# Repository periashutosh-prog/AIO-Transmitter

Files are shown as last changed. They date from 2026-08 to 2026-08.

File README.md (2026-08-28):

<div align="center">

# AIO Transmitter (AIO-TX)

**An open-source, multi-protocol wireless control platform built around the ESP32-C6**



[]()

[Website](https://aio-transmitter.vercel.app) · [Full Documentation](AIO-Transmitter-Documentation.md) · [StrawberryOS Ecosystem](https://github.com/periashutosh-prog/StrawberryOS) · [Smart_Connect Library](https://github.com/periashutosh-prog/Smart-Connect)

</div>

---

## What is AIO-TX?

AIO Transmitter is a universal wireless control interface — not a remote built for one job, but a modular platform that adapts to whatever you're building: an RC vehicle, a robot, a wireless HID peripheral, or a custom ESP-based project of your own.

It's built around the **ESP32-C6**, giving it native support for **WiFi 6, Bluetooth Low Energy, and ESP-NOW** in one board, plus a standalone **0.96" OLED interface** for configuring modes, profiles, and control mappings without ever needing a laptop or companion app.

The platform is designed for two audiences at once: makers and developers who want to fork the fully open hardware and firmware, and beginners who can start controlling something in minutes using preset protocol profiles with no wireless-protocol expertise required.

---

## ✅ Key Features

- **Multi-protocol wireless communication** — WiFi 6, BLE, and ESP-NOW on a single board, with CAN Bus planned for REV 3.0
- **Dual pairing modes** — a fast, unauthenticated **ESP-NOW** mode for trusted low-latency setups, and a PIN-authenticated **Smart Connect** mode for secured sessions
- **Standalone onboard UI** — a 0.96" OLED handles mode switching, WiFi setup, live telemetry, and built-in apps, with no external device required
- **BLE HID emulation** — the same hardware functions as a wireless mouse, keyboard, or media remote for PCs, TVs, and mobile devices
- **17 tactile inputs** — dual D-pads, dual simulated analog channels, and system controls, all read through a single I2C MCP23017 expander (plus one native-GPIO system button)
- **Live link-quality telemetry** — round-trip ping and packet-loss percentage, tracked and shown in real time during an active session
- **Command-silence watchdog** — both transmitter and receiver detect a stalled link and safely end the session, instead of a controlled device executing a stale last command indefinitely
- **Rechargeable battery system** — USB-C charging, with REV 2.0 adding integrated I2C battery telemetry
- **Open, extensible receiver ecosystem** — the companion [`Smart_Connect`](https://github.com/periashutosh-prog/Smart-Connect) library (ESP32 + ESP8266) lets anyone build a compatible receiver — for a robot, an RC car, or any project of their own — with almost no glue code

---

## 🧩 Hardware Revisions

| | REV 1.0 | REV 2.0 |
|---|---|---|
| **Approach** | Module-based (proves the concept) | Discrete-IC based (production-oriented redesign) |
| **MCU** | Seeed XIAO ESP32-C6 breakout | Bare ESP32-C6-MINI-1U module, custom PCB |
| **Power management** | TP4056 charger + MT3608 boost | IP5306-I2C (charge + boost + battery telemetry) |
| **Antenna** | Onboard PCB trace only | Onboard trace + external IPEX-to-SMA option |
| **Enclosure** | SLA resin | CNC-machined aluminum |

REV 2.0 exists specifically to bridge REV 1.0 and REV 3.0: REV 1.0 proved the concept using off-the-shelf modules, and REV 3.0's goal — full CAN Bus modularity with plug-and-play expansion — requires the discrete-IC design competency REV 2.0 is built to develop.

Full architecture, pairing flow, and design rationale: see [AIO-Transmitter-Documentation.md](AIO-Transmitter-Documentation.md).

---

## 🚗 Receiver Ecosystem

AIO-TX is only half the system — the [`Smart_Connect`](https://github.com/periashutosh-prog/Smart-Connect) library is the receiver-side counterpart, available for both **ESP32** and **ESP8266**. It handles advertising, handshake, PIN authentication, and telemetry replies, so a receiver project only needs to implement its own control logic (driving motors, actuators, etc.) on top of it.

An example receiver — an ESP8266-based RC car using an L298N motor driver — is part of this ecosystem, demonstrating full differential steering (forward/back/left/right), live motor-status telemetry back to the transmitter, and an automatic failsafe that cuts motors if the wireless link drops.

---

## 🚀 Getting Started

1. **Get the PCB files** — fabricate from the schematics in `Hardware Design Files/` via JLCPCB or any manufacturer.
2. **Assemble the board** — REV 1.0 is hand-solderable; a full BOM is provided.
3. **Flash the firmware** — compile `AIO_Transmitter.ino` yourself, or use the web-based flashing tool at [aio-transmitter.vercel.app](https://aio-transmitter.vercel.app).
4. **Print the enclosure** — design files included.

Full step-by-step build instructions: [AIO-Transmitter-Documentation.md](AIO-Transmitter-Documentation.md#-how-to-make-aio-transmitter-rev-10).

---

## 🌱 Part of the StrawberryOS Ecosystem

AIO-TX is built on shared firmware architecture and design language from [**StrawberryOS**](https://github.com/periashutosh-prog/StrawberryOS), an open ecosystem of modular embedded devices — including an earlier project, **StrawberryWatch** (originally QuantumWatch), on [OSHWLab](https://oshwlab.com/periashutosh/quantumwatch).

---

## 🏆 EasyEDA Spark 2026

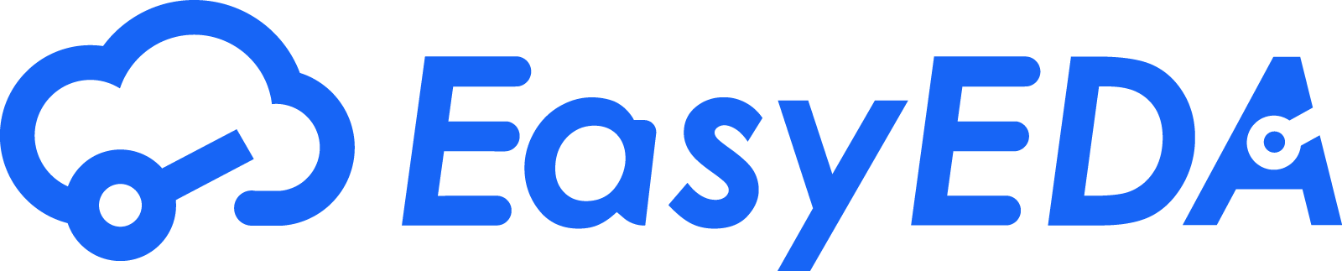
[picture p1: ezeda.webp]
EasyEDA (https://oshwlab.com/activities/easyeda-spark-2026?inviter=periashutosh)


This project is proudly participating in **[EasyEDA Spark 2026](https://oshwlab.com/activities/easyeda-spark-2026?inviter=periashutosh)** — an open-source hardware competition backed by an **$85,000 prize pool**, with free PCB, 3D printing, and CNC manufacturing support for eligible projects.

If you're building your own open-source hardware project — whether it's a fully custom board like AIO-TX or something just getting off the ground — it's well worth checking out. Sponsorship covers real manufacturing costs, not just recognition, which made a genuine difference in getting REV 2.0 of this project built.

👉 **[Join EasyEDA Spark 2026](https://oshwlab.com/activities/easyeda-spark-2026?inviter=periashutosh)**

---

## 📄 License

AIO-TX firmware and hardware are licensed under **GNU GPLv3**. Personal, educational, and non-commercial use only — see [LICENSE](LICENSE) for details.

This project is provided as-is for educational and experimental purposes: not certified for production/commercial use, no warranties, and users assume all risk associated with building and operating the device. Always follow local electrical and RF/radio regulations in your region.

---

## 📬 Links

- **Website:** [aio-transmitter.vercel.app](https://aio-transmitter.vercel.app)
- **Full Documentation:** [AIO-Transmitter-Documentation.md](AIO-Transmitter-Documentation.md)
- **Issues / Contributing:** [github.com/periashutosh-prog/AIO-Transmitter/issues](https://github.com/periashutosh-prog/AIO-Transmitter/issues)
- **Smart_Connect (receiver library):** [github.com/periashutosh-prog/Smart-Connect](https://github.com/periashutosh-prog/Smart-Connect)
- **StrawberryOS:** [github.com/periashutosh-prog/StrawberryOS](https://github.com/periashutosh-prog/StrawberryOS)

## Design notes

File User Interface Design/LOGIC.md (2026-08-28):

# AIO-Transmitter UI Logic For Claude

### 

* #### Screen Definition

Page 1 --> Boot Screen

Page 2 --> Option Screen

Page 3 --> Transmitter

Page 4 --> Scanning

Page 5 --> Search Results

Page 6 --> Pairing Page

Page 7 --> Connected!

Page 8 --> Status

Page 9 --> Control Panel

Page 10 --> Telemetry

Page 11 --> Terminate Session

Page 12 --> Terminating Session

Page 13 --> Applications

Page 14 --> Connection Failed

* #### Button and Pin Definition

\*Bold indicates that the pin is directly wired to ESP32 GPIO.

ANALOG\_1\_UP GPB3

ANALOG\_1\_DOWN GPA7

DPAD\_1\_UP GPA0

DPAD\_1\_DOWN GPA4

DPAD\_1\_LEFT GPB6
DPAD\_1\_RIGHT GPA1

DPAD\_1\_CENTER GPA2

DPAD\_2\_UP GPB0

DPAD\_2\_DOWN GPB5

DPAD\_2\_LEFT GPB7
DPAD\_2\_RIGHT GPB1

DPAD\_2\_CENTER GPB2

ANALOG\_2\_UP GPA6

ANALOG\_2\_DOWN GPB4

SYS\_LEFT GPA5
**SYS\_CENTRE D3 OF XIAO C6**
SYS\_RIGHT GPA3

D0 --> BATTERY VOLTAGE DIVIDER

D1 --> 5V USB Sense

D2 --> Buzzer

D4 --> SDA

D5 --> SCL

D7 --> INTA (MCP23017 Interrupts)

D8 --> INTB (MCP23017 Interrupts)

##### Navigation:

Navigation in the User Interface is based on the left DPAD (DPAD\_1) and should use a focus based system, please refer to StrawberryOS for a deeper understanding

* #### Screen Logic

At the start of the void setup() quickly initialise the I2C and the display and show the boot screen, after that initialise the MCP23017 and other accessories.
After booting, clear the boot screen and display the Page 2 which has 3 options for the user to choose Transmitter, Applications and Settings. And there will be a top status bar for WiFi Bluetooth and ESPNOW (E) at the right of the status bar  there will be a battery icon which is based on the ADC Reading of the D0 pin. I want it to average the ADC reading 1000 times and then the processed output 10 times to give the perfect reading. WiFi and Bluetooth and some part of ESP\_NOW will be managed by the Radio app in the Applications screen (Check StrawberryOS for reference on Radio Application Note: UI in the AIO Transmitter will differ from StrawberryOS). In the Page 2 upon clicking the Applications, the Page 2 should clear and it should open the Applications Page. But if Transmitter is clicked open the Transmitter page which again has 3 options, (including the back button on the top right <--) (Back button in this page should take you back to Page 2) ESP\_NOW and SMART\_CONNECT are two linked but different protocols. ESP\_NOW especially in my case is truly connection free. First, let me explain for the ESP\_NOW communication protocol. After user presses the ESP\_NOW take him to the Scanning page in which the bottom loader should rotate in loops. The receiver will advertise his name with a struct with 3 things, an int, and two sentences. int 1 or 2 is for the ESP\_NOW or the Smart\_Connect. 1 is ESP\_NOW and 2 is Smart\_Connect. AIO-Transmitter reads all the advertised packets (mostly unique ones not try to read duplicate packets and stuck in an infinite loop). In the advertised packets if the int matches the user preference, in this case ESP\_NOW store it temporarily and scan the air till 6 seconds or all the packets are scanned. Now with the scan results go to the Search Results page in which show the Sentence one which is it's MAC Adress and sentence 2 which is receiver's short name. Back button in this page should take you to Page 2. In the top right corner, E is for ESP\_NOW and S is for Smart Connect. Now, in the Search Results page, let user go through the results in the focus navigation manner and if too many results are there use a scrolling algorithm to scroll through the results. When the user selects his preference take him to the Pairing Page. In the Pairing page back button takes you to the Scanning page and re-scan again and everywhere I want the Focus Nav to apply for the <-- button too. Anyways for the pairing logic for ESP\_NOW first the Transmitter sends a packet about itself like the mac address and its name AIO-Transmitter and then the receiver sends an acknowledgement, if no ACK then re-transmit till 3 times then throw an error (Page 14) for 5 seconds then come back to the Page 2. If ACK is received then wait till 10 seconds for the Receiver to send a Connection Ok! kinda packet (not exactly connection ok!, but you handle the machine language). Then take user to Connected! and every packet should have an int at top even if its receiver or transmitter so both devices can easily identify what the other device trying to tell, like lets say Transmitter sent the Connection?? packet and Receiver parses that expecting its the Command packet that shouldn't be the case. So Connection?? has int 1 (example) then the receiver reads that and processes and sends Connection Ok! (ID 1 example dont use same until I approve in the implementation plan) then after this Connection Ok! Transmitter uses ID xyz and transmits the commands. 

Wait in Connected! for 5 seconds then head to control panel. Here is where the actual transmission starts, under the transmission ID int, send an extremely light packet that contains bit values of the 10 DPAD buttons and 2 analog values 0-100. I did not develop the UI for settings yet, that is gonna have the frequency of transmission 10Hz 20Hz or extremely fast 50Hz. 

Now receiver should immediately send a telemetry packet after receiving the command packet. The ACK will be used as Raw Ping and the Telemetry Packet as normal Ping. To switch btwn the screens in the active transmitter mode we use the SYS LEFT and SYS RIGHT, default is Control Panel, If i click SYS Left I go to Status, if I click right I go to transmitter then if i click right I go to Telemetry Page. In this the telemetry packet gets parsed and the actual content the actual string gets displayed here. To terminate the session ie. stop the transmitter mode and return to page 2, I gotta long press the SYS\_CENTRE then it will show Terminate Session page then if yes clicked show the Terminating Session. In that send a packet to the receiver with all values set to default/0 and then send a closing packet and just end the transmitter mode and go back to page 2. If no clicked just resume normally. And one important logic part, if I am in Transmitter mode and in some other page like Status it should still transmit based on the inputs I give. 

So, Thats it for now, I will update this markdown file when new features are developed. 

Last Updated on: 03:05 14-06-2025. 

---

# ESP_NOW Transmitter Protocol (finalized 2026-06-27)

## Locked-in decisions

- **TX builds both ends.** Receiver firmware will be a `Smart_Connect.h` library, built later. For now: transmitter only.
- **Entering ESP_NOW or SMART_CONNECT forces WiFi STA OFF first** (so ESP-NOW is free to use any channel; avoids the shared-channel constraint with WiFi UDP mode).
- **Every packet's first field is `int pkt_id`** so each side knows which struct to parse it as. ESP-NOW transmits a raw byte buffer (<=250 B); we cast these structs to/from it. The sender's MAC arrives free in the receive callback, but advertising/hello packets also carry it in-payload for self-containment.
- **ESP_NOW and SMART_CONNECT have entirely separate struct sets.** The block below is the ESP_NOW set. Smart Connect's structs are TBD (defined when its flow is built).

## ESP_NOW packet IDs

| ID | Name | Direction | Meaning |
|----|---|---|---|
| 10 | PKT_ADVERTISE | RX -> air (2Hz) | Receiver advertising {mode, mac, name} |
| 20 | PKT_HELLO | TX -> RX | "Connect??" — TX introduces itself |
| 21 | PKT_HELLO_ACK | RX -> TX | Receiver acknowledges the hello |
| 22 | PKT_CONN_OK | RX -> TX, then TX -> RX | RX: "Connection Ok!"; TX echoes 22 back to confirm receipt |
| 30 | PKT_CMD | TX -> RX | Live control frame (buttons + 2 analog) |
| 40 | PKT_TELEMETRY | RX -> TX | Telemetry string reply |
| 99 | PKT_CLOSE | TX -> RX | Session teardown |

`mode` field: 1 = ESP_NOW, 2 = SMART_CONNECT.

## ESP_NOW structs (ESP32, authoritative)

```cpp
#define PKT_ADVERTISE   10
#define PKT_HELLO       20
#define PKT_HELLO_ACK   21
#define PKT_CONN_OK     22
#define PKT_CMD         30
#define PKT_TELEMETRY   40
#define PKT_CLOSE       99

struct __attribute__((packed)) AdvertisePacket {
  int  pkt_id;       // = PKT_ADVERTISE (10)
  int  mode;         // 1 = ESP_NOW, 2 = SMART_CONNECT
  char mac[18];      // "AA:BB:CC:DD:EE:FF\0"
  char name[20];     // "RC-Car\0"
};

struct __attribute__((packed)) HelloPacket {
  int  pkt_id;       // = PKT_HELLO (20)
  char mac[18];      // TX own MAC
  char name[20];     // "AIO-Transmitter\0"
};

struct __attribute__((packed)) AckPacket {
  int  pkt_id;       // PKT_HELLO_ACK (21) or PKT_CONN_OK (22)
};

struct __attribute__((packed)) CommandPacket {
  int      pkt_id;   // = PKT_CMD (30)
  uint16_t buttons;  // bits 0-4: DPAD1, bits 5-9: DPAD2
  byte     analog1;  // 0-100
  byte     analog2;  // 0-100
};

struct __attribute__((packed)) TelemetryPacket {
  int  pkt_id;       // = PKT_TELEMETRY (40)
  char data[64];     // "BAT:87% SPD:42 DIR:FWD\0"
};

struct __attribute__((packed)) ClosePacket {
  int  pkt_id;       // = PKT_CLOSE (99)
};
```

## ESP_NOW flow (transmitter side)

1. **Enter** (ESP_NOW tile): WiFi STA off -> `esp_now_init` -> register broadcast peer -> Scanning page.
2. **Scanning:** listen for `AdvertisePacket` with `mode == 1`. Dedup by MAC (receiver repeats at 2Hz). Collect unique advertisers for a >=3s window. (Note: "until all packets read" isn't deterministic over the air, so 3s is the collection window.)
3. **Results:** real list of discovered `{mac, name}`, focus-nav + scroll. `<--` -> Page 2.
4. **Pairing** (after select): handshake below. `<--` -> back to Scanning (re-scan).
5. **Handshake:**
   - TX -> `HelloPacket(20)`. Wait 3s for `HELLO_ACK(21)`.
   - No ack in 3s -> retransmit. **Max 3 attempts.** All fail -> **Connect Failed** page (5s) -> Page 2.
   - On `HELLO_ACK(21)`: wait up to **10s** for `CONN_OK(22)`. Timeout -> Connect Failed -> Page 2.
   - On `CONN_OK(22)`: TX -> `AckPacket(22)` back to RX (confirm). -> **Connected!** (5s) -> Control Panel.
6. **Active session:** send `CommandPacket(30)` to paired MAC at `espNowFreqHz` (Settings). RX replies `TelemetryPacket(40)`.
   - **Raw Ping** = ESP-NOW send-callback ACK latency. **Ping** = command->telemetry round-trip.
   - SYS_LEFT/RIGHT switch Status / Control / Telemetry. Transmission continues on every page.
7. **Terminate:** long-press SYS_CENTRE -> Terminate? -> YES sends a zeroed `CommandPacket` + `ClosePacket(99)`, tears down ESP-NOW -> Page 2.

## SMART_CONNECT packet IDs

| ID | Name | Direction | Meaning |
|----|---|---|---|
| 50 | SC_PKT_ADVERTISE | RX -> air (2Hz) | Receiver advertising {mode=2, mac, name} |
| 51 | SC_PKT_CONNECT_REQ | TX -> RX | "Connect??" — TX introduces itself |
| 52 | SC_PKT_PARTIAL_OK | RX -> TX | "Enter PIN" — RX generates & shows 4-digit code |
| 53 | SC_PKT_PIN_SUBMIT | TX -> RX | TX sends user-entered 4-digit PIN |
| 54 | SC_PKT_CONNECT_OK | RX -> TX | PIN matched, connection established |
| 55 | SC_PKT_CONNECT_FAIL | RX -> TX | Wrong PIN |
| 30 | PKT_CMD | TX -> RX | Reused — same CommandPacket as ESP_NOW |
| 40 | PKT_TELEMETRY | RX -> TX | Reused — same TelemetryPacket as ESP_NOW |
| 99 | PKT_CLOSE | TX -> RX | Reused — same ClosePacket as ESP_NOW |

## SMART_CONNECT structs (ESP32, authoritative)

```cpp
#define SC_PKT_ADVERTISE    50
#define SC_PKT_CONNECT_REQ  51
#define SC_PKT_PARTIAL_OK   52
#define SC_PKT_PIN_SUBMIT   53
#define SC_PKT_CONNECT_OK   54
#define SC_PKT_CONNECT_FAIL 55

struct __attribute__((packed)) ScAdvertisePacket {
  int  pkt_id;       // = SC_PKT_ADVERTISE (50)
  int  mode;         // always 2 (SMART_CONNECT)
  char mac[18];      // "AA:BB:CC:DD:EE:FF\0"
  char name[20];     // "RC-Car\0"
};

struct __attribute__((packed)) ScConnectReqPacket {
  int  pkt_id;       // = SC_PKT_CONNECT_REQ (51)
  char mac[18];      // TX own MAC
  char name[20];     // "AIO-Transmitter\0"
};

struct __attribute__((packed)) ScPartialOkPacket {
  int  pkt_id;       // = SC_PKT_PARTIAL_OK (52)
};

struct __attribute__((packed)) ScPinSubmitPacket {
  int  pkt_id;       // = SC_PKT_PIN_SUBMIT (53)
  int  pin;          // 4-digit code 0000-9999
};

struct __attribute__((packed)) ScConnectOkPacket {
  int  pkt_id;       // = SC_PKT_CONNECT_OK (54)
};

struct __attribute__((packed)) ScConnectFailPacket {
  int  pkt_id;       // = SC_PKT_CONNECT_FAIL (55)
};
```

## SMART_CONNECT flow (transmitter side)

1. **Enter** (SMART CONNECT tile): WiFi STA off -> `esp_now_init` -> register broadcast peer -> Scanning page.
2. **Scanning:** listen for `ScAdvertisePacket` with `mode == 2`. Dedup by MAC. Collect for >=3s.
3. **Results:** list of discovered `{mac, name}`, focus-nav + scroll. `<--` -> Page 2.
4. **Connecting (1st):** TX -> `ScConnectReqPacket(51)`. Wait for `SC_PARTIAL_OK(52)`. Timeout -> Failed.
5. **Enter PIN:** RX has generated a 4-digit code and is showing it on its own OLED. TX shows 4-digit entry screen.
6. **PIN submit:** User enters PIN -> TX -> `ScPinSubmitPacket(53)`.
7. **Authenticating (2nd):** Wait for response:
   - `SC_PKT_CONNECT_OK(54)` -> **Connected!** -> Control Panel.
   - `SC_PKT_CONNECT_FAIL(55)` -> **Failed** -> Page 2.
8. **Active session:** same as ESP_NOW — `CommandPacket(30)` at configured Hz, `TelemetryPacket(40)` replies.
9. **Terminate:** same as ESP_NOW — `ClosePacket(99)`.

## Resolved ambiguities (defaults — change if wrong)

- Final TX->RX confirmation after CONN_OK reuses `AckPacket{pkt_id = 22}` (no new ID), disambiguated by sender MAC.
- CONN_OK wait timeout = 10s (no retransmit; RX is the sender).
- Scan window = 3s, dedup by MAC.

Last Updated on: 2026-06-27 (Smart Connect protocol spec added).

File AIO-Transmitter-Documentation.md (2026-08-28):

# AIO-Transmitter Documentation

## 📋 Table of Contents

- [What Exactly is AIO-Transmitter?](#what-exactly-is-aio-transmitter)
- [Introduction to the Idea](#introduction-to-the-idea)
- [Product Functions, Application Scenarios & Design Details](#-product-functions-application-scenarios--design-details)
- [System Architecture](#-system-architecture)
- [How AIO-Transmitter Actually Works](#-how-aio-transmitter-actually-works)
- [Hardware Revisions](#-hardware-revisions)
- [Technical Specifications](#-technical-specifications)
- [Getting Started — How to Make AIO-Transmitter (REV 1.0)](#-how-to-make-aio-transmitter-rev-10)
- [Firmware & Software](#-firmware--software)
- [Comparison with Other Systems](#-comparison-with-other-systems)
- [License & Disclaimer](#-license--disclaimer)
- [Documentation, Contributing, Contact & Acknowledgments](#-documentation-contributing-contact--acknowledgments)

---

## What Exactly is AIO-Transmitter?

AIO Transmitter, also known as AIO-TX, is a wireless transmitter platform. AIO stands for **All In One**, which describes the core philosophy of the project: although it functions as a transmitter, it is capable of far more than a typical single-protocol transmitter.

AIO-TX is powered by the **ESP32-C6**, a chip well known for its strength in wireless communication. It supports three wireless protocols and one wired protocol:

- **WiFi** (WiFi 6) — for internet connectivity, security, and high reliability
- **Bluetooth Low Energy (BLE)** — for connecting directly to smart devices and phones
- **ESP-NOW** — for ultra-low-latency, peer-to-peer communication
- **Controller Area Network (CAN)** — a wired, industrial-grade protocol (REV 3.0 exclusive)

This breadth means AIO-TX is designed to fit almost any wireless project. Whether you're building a low-latency RC car, a robot that demands high security, or simply want a transmitter that connects seamlessly to your phone, AIO Transmitter is built to handle it.

The platform is intentionally designed with two types of users in mind. Senior developers and experienced makers have the freedom to tailor the firmware and hardware to their exact needs, since both are fully open source. At the same time, beginners can start using AIO-TX almost immediately thanks to preset profiles for each protocol, meaning no deep wireless protocol knowledge is required to get started.

### ✅ Key Features

- ✅ Multi-protocol: WiFi 6, BLE, ESP-NOW, CAN (REV 3.0)
- ✅ Dual pairing modes — ESP-NOW (direct, no auth) and Smart Connect (PIN-authenticated)
- ✅ 17-button input (dual D-pad, dual analog, system controls) via MCP23017 I2C expander
- ✅ Onboard 0.96" OLED display with tile-based UI, no companion app or laptop required
- ✅ Rechargeable Li-ion battery with USB-C charging
- ✅ Fully open source — hardware and firmware
- ✅ Companion `Smart_Connect` receiver library (ESP32 + ESP8266) for building your own receivers
- ✅ No vendor lock-in

---

## Introduction to the Idea

The idea behind AIO-TX came from wanting something more than just another remote controller. Most transmitters are built to do one job and do it well, but they stop there. AIO-TX was designed to break out of that single-function mold and become a modular system that adapts to whatever you're building, whether that's controlling a robot, running an RC setup, acting as wireless gaming input, or reading data from sensors.

What really sets the project apart is how it brings ESP-NOW, BLE, and WiFi together on one board alongside modular hardware expansion. That combination means AIO-TX isn't limited to just talking to one device, it can handle direct one-to-one control just as easily as distributed communication across multiple nodes.

The onboard OLED display plays a big part in making this practical day-to-day, since it lets you configure settings and switch modes in real time without needing a laptop or any external software running alongside it. Looking ahead, the firmware is being built with room to grow, including structured control profiles and an early concept of OS-like behavior through StrawberryOS integration.

If you want to dig deeper into StrawberryOS, you can check it out here:
- [StrawberryOS GitHub Repository](https://github.com/periashutosh-prog/StrawberryOS)
- [StrawberryWatch on OSHWLab](https://oshwlab.com/periashutosh/quantumwatch)

And for everything related to the current project, the official page is here:
[AIO-Transmitter Website](https://aio-transmitter.vercel.app)

---

## 🎯 Product Functions, Application Scenarios & Design Details

### Product Functions

- **Multi-protocol wireless transmission** — ESP-NOW for ultra-low-latency peer-to-peer control, BLE for direct pairing with phones/tablets/PCs, WiFi 6 for network connectivity, and CAN (REV 3.0) for wired industrial-grade links.
- **Dual-mode receiver pairing** — an open ESP-NOW mode for fast, trusted-environment connections, and a PIN-authenticated Smart Connect mode for secured sessions.
- **Full physical control surface** — 17 tactile buttons total: 2 D-pads, 2 simulated analog channels (as up/down button pairs), and 3 system controls, nearly all read through a single I2C-based MCP23017 expander.
- **Standalone onboard UI** — a tile-based OLED interface for navigating modes, entering WiFi credentials, running built-in apps (e.g. Timer), and adjusting settings, with no laptop or companion app required.
- **Live link-quality telemetry** — round-trip ping time and packet-loss percentage are tracked and displayed in real time during an active session, alongside whatever telemetry (battery, speed, sensor data) the receiver reports back.
- **Command-silence watchdog** — both transmitter and receiver monitor for a stalled link and safely tear down the session if communication stops, instead of letting a controlled device keep executing a stale last command.
- **Power management** — automatic display dimming on inactivity, plus a manual long-press shutdown into light sleep with wake-on-button-press, so the device can be put to sleep and resumed without a full reboot.
- **Rechargeable battery system** — Li-ion battery with USB-C charging (REV 1.0: TP4056 linear charger; REV 2.0: IP5306-I2C with pass-through charge/discharge and I2C battery telemetry).
- **Open extensibility** — companion `Smart_Connect` Arduino library (ESP32 + ESP8266) lets anyone build a compatible receiver with almost no glue code, and exposed I2C/power test pads allow hardware expansion on REV 1.0.

### Application Scenarios

- **RC vehicles and drones** — ESP-NOW mode delivers near-instant control input where every millisecond of latency matters.
- **Robotics projects** — dual D-pad and analog channel input for driving or arm control, with live telemetry (battery level, speed, sensor readings) shown directly on the transmitter's own OLED.
- **Wireless gaming and general input** — BLE mode lets AIO-TX connect straight to a phone, tablet, or PC as a control peripheral, with no receiver hardware needed at all.
- **Distributed IoT/sensor setups** — WiFi connectivity combined with ESP-NOW's peer-to-peer nature lets a single transmitter relay commands to, or pull data from, multiple nodes.
- **Security-conscious deployments** — Smart Connect's PIN-authenticated pairing is the right choice anywhere an open, unauthenticated ESP-NOW broadcast would be a liability.
- **Education and maker projects** — preset protocol profiles mean beginners can get moving without wireless-protocol expertise, while the fully open firmware gives experienced developers a base to fork and customize.
- **Field use without a laptop** — since mode switching, WiFi setup, and telemetry all live on the onboard OLED, AIO-TX is usable entirely standalone, away from a desk.

### Design Details

- **Shared single I2C bus** — the SSD1306 OLED (`0x3C`) and MCP23017 expander (`0x20`) sit on the same bus, keeping wiring centralized and freeing up native ESP32-C6 GPIOs. The trade-off is that 16 of the 17 tactile buttons (both D-pads, both analog channels, and two of the three system controls) have to be read via I2C polling rather than direct GPIO interrupts, so the firmware does edge-detection in software to distinguish a fresh "just pressed" event from a button simply being held.
- **Power button on native GPIO, deliberately** — the System Center/Power button is the one control wired directly to a native ESP32-C6 pin instead of through the MCP23017. This is intentional: it lets the button keep working as a wake source even while the device is in light sleep and the I2C bus itself is powered down.
- **Channel pinning before any handshake** — both pairing modes require transmitter and receiver to lock to the same WiFi channel first. Skipping this step lets ESP-NOW broadcast packets through while silently breaking the unicast handshake, so channel pinning always happens before any other radio setup.
- **Screen-state-machine UI** — a single `ScreenState` variable plus one draw function per screen drives the entire interface. Transitions are done with simple offset-based slide animation rather than a graphics library, keeping the UI responsive within the ESP32-C6's flash/RAM budget.
- **Retry-based pairing reliability** — Smart Connect retransmits connection requests and PIN submissions every 700ms until acknowledged, so a single dropped packet on a noisy 2.4GHz link doesn't stall the pairing process.
- **Module-based REV 1.0, discrete-IC REV 2.0** — REV 1.0 deliberately uses pre-built modules (XIAO ESP32-C6 breakout, TP4056 charger) so it can be hand-soldered without specialized equipment. REV 2.0 moves to discrete ICs (bare ESP32-C6 module, IP5306-I2C power management) for a smaller, more production-oriented board, trading easy hand-assembly for a tighter, more integrated design.
- **Optional external antenna (REV 2.0)** — the IPEX-to-SMA antenna connector is provisioned but optional; the board still functions fully on its onboard PCB antenna, with the connector there for users who specifically need extended range.

---

## 🏗️ System Architecture

AIO-TX centers around the **ESP32-C6** as the main controller, with all physical inputs and the display sharing a single I2C bus:

- **ESP32-C6 (MCU)** — handles all wireless protocols (WiFi, BLE, ESP-NOW), runs the UI state machine, and drives the OLED.
- **MCP23017 (I2C GPIO expander, address `0x20`)** — 16 of the 17 tactile buttons (both D-pads, both analog channels, and two of the three system controls) route through this expander rather than direct MCU GPIOs, freeing up native pins and keeping wiring centralized.
- **SSD1306 OLED (I2C, 128×64)** — shares the same I2C bus as the MCP23017, drives the tile-based home screen and all sub-menus.
- **Power management** — REV 1.0 uses a TP4056 linear charger; REV 2.0 upgrades to an IP5306-I2C power-bank IC with pass-through charge/discharge and I2C battery telemetry.

**Pairing modes:**
- **ESP-NOW** — direct broadcast/unicast, no authentication, lowest latency. Best for quick setups and trusted environments.
- **Smart Connect** — PIN-authenticated pairing over the same ESP-NOW radio. The receiver generates a random PIN on its own display; the transmitter must submit the matching PIN before a session opens.

Any receiver built with the companion [`Smart_Connect`](https://github.com/periashutosh-prog/Smart_Connect) Arduino library (ESP32 and ESP8266 supported) pairs with AIO-TX out of the box, with no extra glue code required.

---

## ⚙️ How AIO-Transmitter Actually Works

This section walks through what the firmware is actually doing, from the moment you power the device on to an active control session.

### 1. Boot & Initialization

On power-up, the ESP32-C6 brings up the I2C bus first, since everything else on the board — the OLED and the MCP23017 — depends on it. The OLED initializes and immediately shows a boot screen while the MCP23017 is configured with all 16 of its pins set to input-pullup, so every button reads HIGH (unpressed) by default and pulls LOW only when physically pressed. A short ascending boot chime plays through the buzzer, and the firmware lands on the home screen — a tile grid for Transmitter, Applications, and Settings.

### 2. Reading Input

Rather than wiring buttons directly to the microcontroller, 16 of the 17 tactile buttons (both D-pads, both analog channels, and two of the three system controls) route through the MCP23017 I/O expander over I2C. Every pass through the main loop, the firmware reads the expander's two GPIO banks in one I2C transaction, compares the result against the previous read to detect "just pressed" edges (not just "currently held"), and updates the UI accordingly. This is why menu navigation feels immediate — the button state is fresh every single loop iteration, not polled on a slow timer. The System Center/Power button is the one exception: it's wired to a native ESP32 GPIO rather than the expander, specifically so it can double as a wake source when the device is asleep and the I2C bus itself is powered down.

### 3. The UI

The interface is a screen-state machine — one `ScreenState` value tracks exactly what's on screen at any moment, and each screen has its own draw function. Moving between screens isn't an instant cut; the firmware slides the outgoing and incoming screens past each other horizontally or vertically, giving the tile-based menu its animated feel without needing a graphics library beyond what the OLED driver already provides.

### 4. Pairing — Two Different Trust Models

AIO-TX supports two ways to connect to a receiver, both riding on the same ESP-NOW radio, both requiring transmitter and receiver to first pin themselves to the same WiFi channel (channel 1) — without this, ESP-NOW's unicast handshake silently fails even though broadcast packets still get through, which is why channel pinning happens before anything else in the radio setup.

- **ESP-NOW mode:** receivers running in this mode broadcast their own advertising packets; the transmitter passively scans and listens, building a list of nearby receivers by name — it does not broadcast first. You manually select one from that list, and only then does the transmitter send a unicast **Hello** packet directly to that specific receiver. The receiver replies with a **Hello_ACK**, followed by a **CONN_OK** once it's ready — the transmitter echoes CONN_OK back to confirm, and the session opens. No PIN, no encryption at any step — fastest to set up, intended for trusted environments where you already know what you're connecting to.
- **Smart Connect mode** builds on the same scan-and-select flow with an added authentication layer: after picking a receiver, the transmitter sends a connection request and waits for the receiver's acknowledgment that it's ready for a PIN. Once acknowledged, you're prompted to enter the 4-digit PIN the receiver is displaying on its own screen. The transmitter submits that PIN; only a match unlocks the session — a wrong PIN fails the connection outright. Every connection request and PIN submission is retransmitted every 700ms until a reply arrives, so a single dropped packet over a noisy link doesn't stall the pairing process.

### 5. Active Control & Telemetry

Once connected, the transmitter continuously packs the current DPAD and analog channel state into a formatted command packet and sends it to the receiver. The receiver replies with telemetry — battery level, speed, or whatever the receiver-side sketch chooses to report — which shows up on the transmitter's Telemetry screen. The firmware also tracks round-trip ping time and packet-loss percentage (sent vs. acknowledged) in real time, so you can see link quality directly on the Control screen rather than just guessing. Both sides run a command-silence watchdog — if the transmitter stops sending, the receiver notices and safely tears down the session on its own, rather than a vehicle or robot continuing to execute a stale last command forever.

### 6. Power Management

The firmware tracks inactivity and dims the display after a timeout, but the real power-saving step is manual: holding the System Center/Power button for 3 seconds from the Home or Applications Menu opens a shutdown confirmation. Confirming it plays a short "Shutting Down…" animation, then the ESP32-C6 drops into light sleep with the power button armed as a wake source. A single press wakes the chip back up — not a full reboot, but a resumed execution that replays the boot screen and chime for a consistent "freshly powered on" feel, before returning you exactly to where the sleep/wake cycle left off.

---

## 🧩 Hardware Revisions

| | REV 1.0 | REV 2.0 |
|---|---|---|
| **MCU Module** | Seeed XIAO ESP32-C6 (breakout board) | Bare ESP32-C6 module, directly on PCB |
| **Power Management** | TP4056 linear charger + MT3608 boost | IP5306-I2C (charge + boost + I2C battery telemetry) |
| **Charging** | USB-C, 5V/1A | USB-C, 5V/2A |
| **USB** | Via XIAO's onboard USB-C | Native USB-C sink, on-board CC negotiation |
| **Enclosure** | SLA 9000HE resin case, 8001 translucent resin top | Aluminum CNC case + 9000HE resin cover |
| **Antenna** | Onboard PCB trace (XIAO module) | External via IPEX-to-SMA, screw-on antenna |
| **Approach** | Module-based, hand-solderable | Discrete ICs, custom power/USB circuitry |

---

## 🔧 Technical Specifications

| Specification | Value |
|---|---|
| MCU | ESP32-C6 (WiFi 6, BLE 5, 802.15.4, ESP-NOW) |
| Display | 0.96" OLED, 128×64, SSD1306, I2C |
| I/O Expander | MCP23017, I2C address `0x20` |
| Inputs | 17 tactile buttons — 2 D-pads, 2 simulated analog channels, 3 system controls |
| Battery | Li-ion, rechargeable, 3800mAh |
| Charging (REV 1.0) | USB-C, 5V/1A (TP4056) |
| Charging (REV 2.0) | USB-C, 5V/2A (IP5306-I2C) |
| Wireless Protocols | WiFi 6, BLE, ESP-NOW |
| Wired Protocol | CAN (REV 3.0 exclusive) |
| Wireless Range | 500m (with external antenna) |
| Antenna | Onboard PCB antenna (standard) + external antenna provision via IPEX-to-SMA (optional, extended range) |
| Dimensions | 13.2 × 12.9 × 4 cm |
| Weight | 234g |
| Enclosure (REV 1.0) | SLA resin (9000HE body, 8001 translucent top) |
| Enclosure (REV 2.0) | Aluminum CNC + resin cover |

---

## 🚀 How to Make AIO-Transmitter (REV 1.0)

Since both the hardware design and firmware are open source, building your own AIO-TX REV 1.0 is straightforward.

### 1. Get the PCB Files

Export the PCB design files from the project repository and fabricate them through **JLCPCB**, or any PCB manufacturer of your choice.

### 2. Assemble the Board

REV 1.0 is built using modular components, which means it can be hand-soldered without specialized equipment. If you'd prefer not to solder it yourself, JLCPCB also offers professional assembly services.

A full component list (Bill of Materials) for REV 1.0 is provided separately — please refer to it before ordering parts, to ensure you have everything needed for assembly.

### 3. Flash the Firmware

Once your board is assembled, the next step is uploading the firmware to the **XIAO ESP32-C6** module. You have two options:

- **Compile it yourself** — Download the source code from the [GitHub repository](https://github.com/periashutosh-prog/AIO-Transmitter), compile it, and upload it using your preferred development environment.
- **Flash it directly** — Use the web-based flashing tool available on the [AIO-Transmitter website](https://aio-transmitter.vercel.app/) to flash the firmware straight to your board without needing to set up a development environment.

### 4. Print the Enclosure

Once your PCB is assembled and flashed, print the enclosure (design files provided in the repository) to complete your build.

At this point, your AIO-Transmitter REV 1.0 is fully built and ready to use.

---

## 💻 Firmware & Software

AIO-TX's firmware is a single Arduino sketch (`AIO_Transmitter.ino`) covering:

- Tile-based UI with slide animations, driven off a screen-state machine
- MCP23017 button polling with edge detection
- ESP-NOW transmitter logic (scan, connect, session management, telemetry)
- Smart Connect PIN-pairing flow
- WiFi credential management (scan, connect, saved networks)
- Built-in apps (Timer with ringing alert, and others)
- Power management: boot chime, power-button long-press → shutdown confirmation → light sleep, wake on button press

### Companion Library

Any receiver you build pairs with AIO-TX using the [`Smart_Connect`](https://github.com/periashutosh-prog/Smart_Connect) library — available for both **ESP32** (FreeRTOS task-based) and **ESP8266** (cooperative `tick()`-based). It handles advertising, handshake, PIN authentication, and telemetry, so you only need to write your own control logic.

### Repository Layout

```
aio-transmitter/
├── AIO_Transmitter.ino               # Main firmware
├── AIO-Transmitter-Documentation.md  # Full technical documentation
├── About.md                          # Feature overview
├── Materials.txt                     # Full Bill of Materials (BOM)
├── partitions.csv                    # Custom ESP32 partition table
├── LICENSE                           # GPLv3 (firmware)
└── Hardware Design Files/            # Schematics, Gerbers, BOM
```

---

## 📊 Comparison with Other Systems

| Feature | AIO-TX | LoRa Modules | nRF24L01 | Generic WiFi Modules | Generic DIY Modules |
|---|---|---|---|---|---|
| Onboard UI (display + buttons) | ✅ Built-in | ❌ None | ❌ None | ❌ Rarely | ❌ None |
| Latency | Very low (ESP-NOW) | High | Low | Moderate-high (full WiFi stack) | Depends on build |
| Range | Moderate (WiFi/ESP-NOW class) | Very long (km-scale) | Short-moderate (~100m open air) | Moderate (AP-dependent) | Depends on build |
| Multi-protocol on one board | ✅ WiFi + BLE + ESP-NOW + CAN (REV3) | ❌ LoRa only | ❌ 2.4GHz proprietary only | ❌ WiFi only | ❌ Whatever you wire |
| Pairing/Security | ✅ Smart Connect PIN pairing | Manual/none | Manual/none | Varies | Manual/none |
| Out-of-the-box receiver support | ✅ `Smart_Connect` library | ❌ Build your own stack | ❌ Build your own stack | ❌ Build your own stack | ❌ Build your own stack |
| Setup effort | Low (preset profiles) | High | High | Moderate | Very high |
| Best for | General-purpose control (robotics, RC, IoT) | Long-range, low-bandwidth telemetry | Cheap, simple point-to-point links | Internet-connected devices | Fully custom one-off builds |

AIO-TX isn't trying to out-perform any single radio technology at its own specialty — a dedicated LoRa link will always out-range it, and raw nRF24L01 will always be cheaper. What AIO-TX offers instead is a **complete, ready-to-use platform**: a physical UI, dual pairing modes, and a companion receiver library, so you're not rebuilding the transmitter side from scratch every time you start a new project.

---

## 📄 License & Disclaimer

**AIO-TX Firmware and Hardware** are both licensed under the **GNU General Public License v3 (GPLv3)**.

> ⚠️ **Strictly NO COMMERCIALIZATION TOLERATED.** This project is shared for personal, educational, and non-commercial use only.

### Disclaimer

This project is provided as-is for educational and experimental purposes.

- ⚠️ Not certified for production or commercial use
- ⚠️ No warranties or guarantees provided
- ⚠️ User assumes all risks associated with building and operating this device
- ⚠️ Always follow local electrical and RF/radio regulations in your region

---

## 📚 Documentation, Contributing, Contact & Acknowledgments

### Documentation
- Website: [aio-transmitter.vercel.app](https://aio-transmitter.vercel.app)
- Schematics, Gerbers & BOM: available in `Hardware Design Files/`
- 3D Print Files: available in `3D Print Files/`

### Contributing
Found a bug, have a feature idea, or want to contribute? Open an issue or pull request on GitHub:
[github.com/periashutosh-prog/AIO-Transmitter/issues](https://github.com/periashutosh-prog/AIO-Transmitter/issues)

### Contact
- GitHub: [github.com/periashutosh-prog/AIO-Transmitter](https://github.com/periashutosh-prog/AIO-Transmitter)
- Website: [aio-transmitter.vercel.app](https://aio-transmitter.vercel.app)

### Related Projects
- [StrawberryOS](https://github.com/periashutosh-prog/StrawberryOS)
- [Smart_Connect Library](https://github.com/periashutosh-prog/Smart_Connect)

### Acknowledgments
Built as part of the StrawberryOS ecosystem, with thanks to the open-source Arduino/ESP32 community whose libraries (Adafruit GFX, Adafruit SSD1306, Adafruit MCP23017) made this project possible.

---

*This documentation is a work in progress and will be updated as REV 1.0 development continues and REV 2.0 planning begins.*

Updates can be followed here: [aio-transmitter.vercel.app](https://aio-transmitter.vercel.app/)

AIO-Transmitter

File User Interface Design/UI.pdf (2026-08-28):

# AIO-Transmitter

### Powered by StrawberryOS

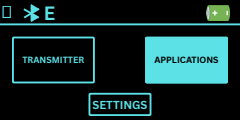
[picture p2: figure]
SETTINGS TRANSMITTER; APPLICATIONS

TRANSMITTER

SCANNING...

E

<-- | TRANSMITTER A4:2B:F7:83:1D:C9 5E:91:D2:4C:6F:38 78:A5:C1:E9:42:B6 D3:6E:9A:27:5B:F4 2F:BC:8D:51:73:AA | AIO-Transmitter RC-Car Keyboard Ashutosh’s Sma... Smartwatch E

<-- | TRANSMITTER 5E:91:D2:4C:6F:38

RC-Car

Pairing With

Authenticating....

E

TRANSMITTER CONNECTED!

STATUS PKT Loss: 2.7% | 🔋

### Raw Ping: 4ms Ping: 10ms RX BAT: 74%

### RSSI: -52 dBm Signal Quality: 89 20Hz RECV:92ms Time: 7m 34s ERR: 18 PKT/s: 48 ESP_NOW

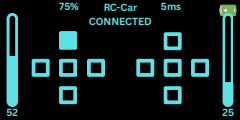
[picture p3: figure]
RC-Car; CONNECTED

TELEMETRY | 🔋

BAT:87% SPD:42 DIR:FWD
STR:+15 THR:78 SIG:-62

TRANSMITTER

## Terminate Session?

YES | NO

TRANSMITTER

## Terminating Session

E

🔋

AI Chatbot Calculator Sci Calculator Radio Modular Expansion

### TRANSMITTER CONNECTED FAILED!

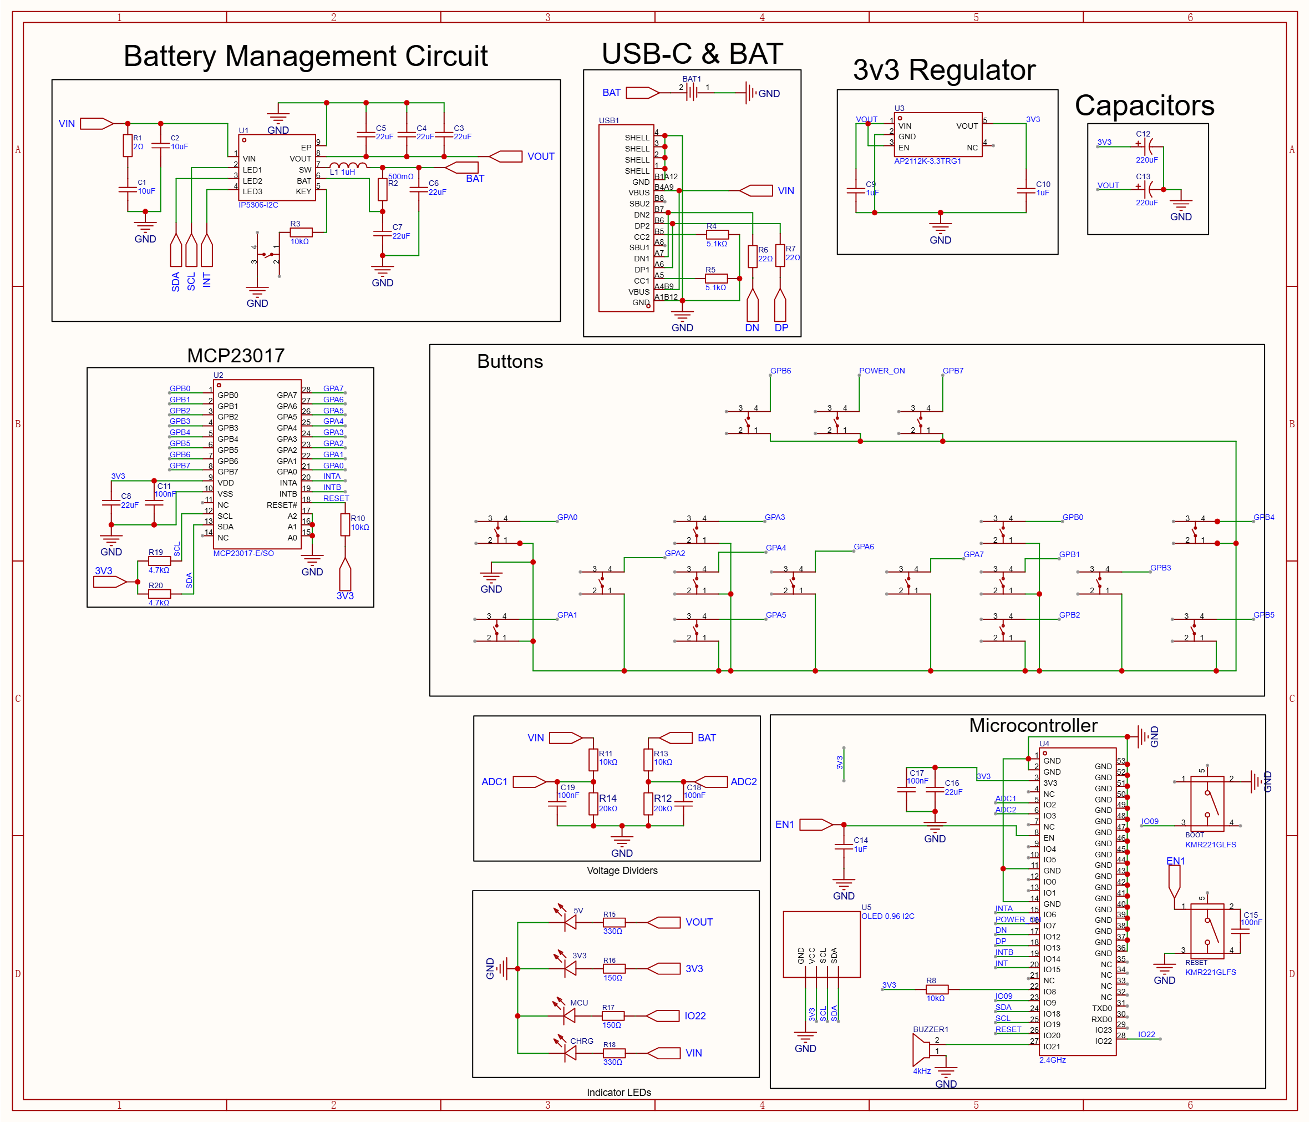
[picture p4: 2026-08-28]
Hardware Design Files/SCH_Schematic4_1-P1_2026-06-18.png

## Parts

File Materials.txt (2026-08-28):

U1 --> XIAO-ESP32-C6
U17 --> MT3608 Module
U18 --> 1000uF 16v Capacitor
U19 --> 0.1uF Ceramic Capacitor
U20 --> 10kΩ Resistor
U21 --> 10kΩ Resistor
U22 --> 20kΩ Resistor
U23 --> 20kΩ Resistor
U24 --> 0.96" I2C OLED Module 
U25 --> TP4056 Module (with Built-in Protection)
U26 --> MCP23017-E/SP DIP Package
U27 --> 0.1uF Ceramic Capacitor
U28 --> 4.7kΩ Resistor
U29 --> 4.7kΩ Resistor
U30 --> 4.7kΩ Resistor
U31 --> 5mm Pitch 5v Buzzer.
 
BAT1 --> SMD 18650 Battery Holder
SW1 to SW19 --> 6x6x6mm Tactile Switches (Height of the switch can be varied to fit the 3D Printed Enclosure)

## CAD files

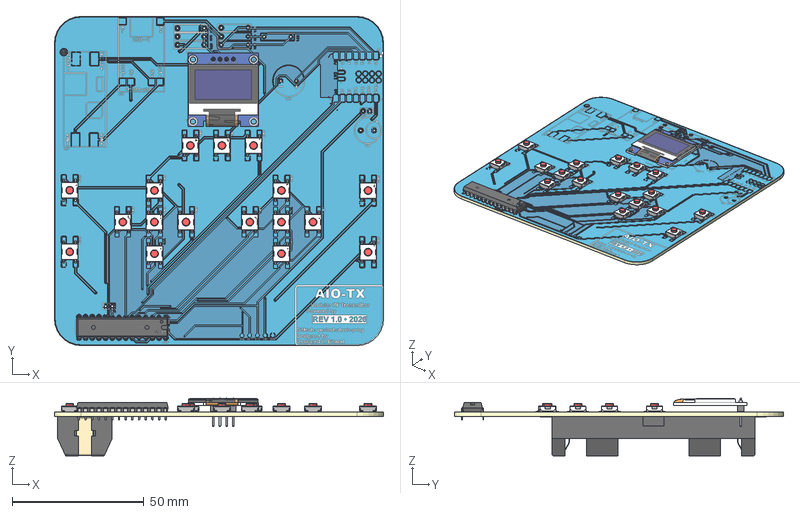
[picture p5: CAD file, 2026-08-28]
Hardware Design Files/PCB 3D File.step
125.0 x 125.0 x 21.9 mm
Board~Llyo
TopCopper~Llyo
BottomCopper~Llyo
TopSilkscreen~Llyo
BottomSilkscreen~Llyo
TopFpcStiffener~Llyo
BottomFpcStiffener~Llyo
OLED 0.96 I2C GND-VCC~OLED-128x64-0.96~Llyo
BATTERY-SMD_18650-1S-L77.1-W20.7-1~BATTERY-SMD_ 18650-1S-L77.1-W20.7-1~Llyo
DIP-28_L34.6-W7.3-P2.54-LS10.2-BL~DIP-28_ L34.6-W7.3-H4.6-P2.54-LS10.2-BL~Llyo
SW-SMD_4P-L6.0-W6.0-P4.50-LS9.0-2~SW-SMD_ 4P-L6.0-W6.0-P4.50-LS11.0~Llyo x 17

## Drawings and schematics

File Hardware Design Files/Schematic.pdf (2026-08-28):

GPIO16_D6_TX 7 | GPIO⁵_MTDI 24 | GPIO⁷_MTDO ²⁵ CHIP_EN ²⁶ BAT 32 GND ²⁷

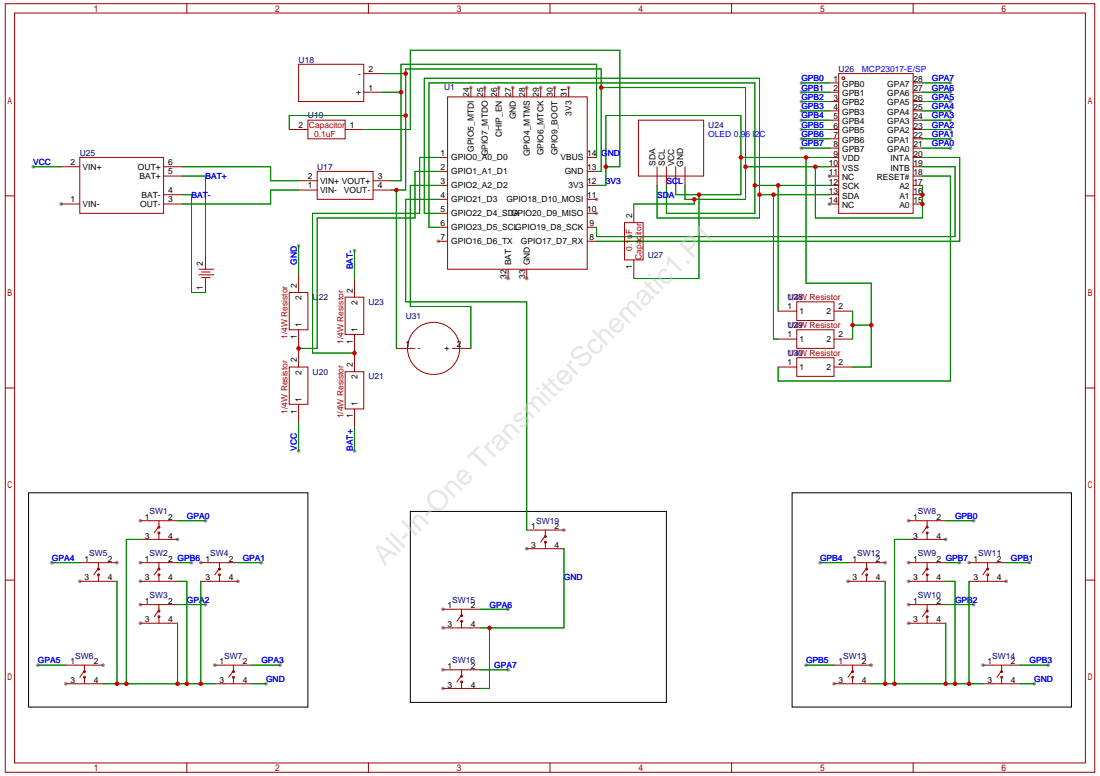
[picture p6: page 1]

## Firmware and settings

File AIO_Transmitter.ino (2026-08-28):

// =============================================================================
// AIO-Transmitter — StrawberryOS Integration
// ESP32-C6 based wireless transmitter with embedded StrawberryOS apps
// =============================================================================

#include <Arduino.h>
#include <Wire.h>
#include <Adafruit_GFX.h>
#include <Adafruit_SSD1306.h>
#include <Adafruit_MCP23X17.h>
#include <WiFi.h>
#include <WiFiUdp.h>
#include <HTTPClient.h>
#include <WiFiClientSecure.h>
#include <Preferences.h>
#include "time.h"
#include <LittleFS.h>
#include <esp_now.h>
#include <esp_idf_version.h>
#include <esp_wifi.h>
#include <esp_sleep.h>
#include <driver/gpio.h>
#include <freertos/semphr.h>
#include <BleCompositeHID.h>
#include <KeyboardDevice.h>
#include <MouseDevice.h>

// =============================================================================
// PACKET IDS — ESP_NOW
// =============================================================================
#define PKT_ADVERTISE   10
#define PKT_HELLO       20
#define PKT_HELLO_ACK   21
#define PKT_CONN_OK     22
#define PKT_CMD         30
#define PKT_TELEMETRY   40
#define PKT_CLOSE       99

// =============================================================================
// PACKET IDS — SMART CONNECT
// =============================================================================
#define SC_PKT_ADVERTISE    50
#define SC_PKT_CONNECT_REQ  51
#define SC_PKT_PARTIAL_OK   52
#define SC_PKT_PIN_SUBMIT   53
#define SC_PKT_CONNECT_OK   54
#define SC_PKT_CONNECT_FAIL 55

// =============================================================================
// STRUCTS — ESP_NOW
// =============================================================================
struct __attribute__((packed)) AdvertisePacket {
  int  pkt_id;       // PKT_ADVERTISE (10)
  int  mode;         // 1 = ESP_NOW
  char mac[18];
  char name[20];
};

struct __attribute__((packed)) HelloPacket {
  int  pkt_id;       // PKT_HELLO (20)
  char mac[18];
  char name[20];
};

struct __attribute__((packed)) AckPacket {
  int  pkt_id;       // PKT_HELLO_ACK (21) or PKT_CONN_OK (22)
};

struct __attribute__((packed)) CommandPacket {
  int      pkt_id;   // PKT_CMD (30)
  uint16_t buttons;  // bits 0-4: DPAD1, bits 5-9: DPAD2
  byte     analog1;  // 0-100
  byte     analog2;  // 0-100
};

struct __attribute__((packed)) TelemetryPacket {
  int  pkt_id;       // PKT_TELEMETRY (40)
  char data[64];
};

struct __attribute__((packed)) ClosePacket {
  int  pkt_id;       // PKT_CLOSE (99)
};

// =============================================================================
// STRUCTS — SMART CONNECT
// =============================================================================
struct __attribute__((packed)) ScAdvertisePacket {
  int  pkt_id;       // SC_PKT_ADVERTISE (50)
  int  mode;         // 2 = SMART_CONNECT
  char mac[18];
  char name[20];
};

struct __attribute__((packed)) ScConnectReqPacket {
  int  pkt_id;       // SC_PKT_CONNECT_REQ (51)
  char mac[18];
  char name[20];
};

struct __attribute__((packed)) ScPartialOkPacket {
  int  pkt_id;       // SC_PKT_PARTIAL_OK (52)
};

struct __attribute__((packed)) ScPinSubmitPacket {
  int  pkt_id;       // SC_PKT_PIN_SUBMIT (53)
  int  pin;          // 4-digit code 0000-9999
};

struct __attribute__((packed)) ScConnectOkPacket {
  int  pkt_id;       // SC_PKT_CONNECT_OK (54)
};

struct __attribute__((packed)) ScConnectFailPacket {
  int  pkt_id;       // SC_PKT_CONNECT_FAIL (55)
};

// -----------------------------------------------------------------------------
// STATUS BAR ICON BITMAPS (8x8 pixels, stored in PROGMEM)
// -----------------------------------------------------------------------------
// WiFi — expanding fan, uses full 8px width so it reads wide, not elongated
//   ........
//   .XXXXXX.   outer arc
//   X......X
//   ..XXXX..   middle arc
//   .X....X.
//   ...XX...   inner arc
//   ........
//   ...XX...   source dot
static const uint8_t PROGMEM wifi_bmp[] = {
  0x00, 0x7E, 0x81, 0x3C, 0x42, 0x18, 0x00, 0x18
};
// Bluetooth — centered rune with continuous vertical spine + crossing diagonals
//   ...X....
//   .X.XX...
//   ..XX.X..
//   ...XX...
//   ..XX.X..
//   .X.XX...
//   ...X....
//   ........
static const uint8_t PROGMEM bt_bmp[] = {
  0x10, 0x58, 0x34, 0x18, 0x34, 0x58, 0x10, 0x00
};

// -----------------------------------------------------------------------------
// DISPLAY CONSTANTS
// -----------------------------------------------------------------------------
#define SCREEN_WIDTH 128
#define SCREEN_HEIGHT 64
#define OLED_RESET -1
Adafruit_SSD1306 display(SCREEN_WIDTH, SCREEN_HEIGHT, &Wire, OLED_RESET);

// -----------------------------------------------------------------------------
// MCP23017 CONFIGURATION
// -----------------------------------------------------------------------------
Adafruit_MCP23X17 mcp;

// ---- Cached + debounced MCP23017 input state --------------------------------
// Every mcp.digitalRead() is a full I2C transaction (address, register, read,
// stop). loop() was issuing 16-22 of them per iteration, which at the current
// loop rate is thousands per second and milliseconds of pure I2C stall each
// pass. readGPIOAB() fetches all 16 inputs in ONE transaction instead, and
// everything else reads from this cache via mcpBtn(). Implementations sit
// next to readButtons() further down; only the shared state lives here.
//
// Debouncing matters now too: at the old ~30Hz loop the 33ms period masked
// contact bounce for free. At a few hundred Hz it no longer does, so a single
// physical press would otherwise register as several edges. A bit is only
// committed once it has held the same value for MCP_DEBOUNCE_MS.
uint16_t mcpStable = 0xFFFF;              // 1 = released (pull-up), 0 = pressed
unsigned long mcpBitChangeTime[16] = {0};
const unsigned long MCP_DEBOUNCE_MS = 15;

// MCP23017 Pin Mappings — Port A
#define DPAD_1_UP       0   // GPA0
#define DPAD_1_RIGHT    1   // GPA1
#define DPAD_1_CENTER   2   // GPA2
#define SYS_RIGHT       3   // GPA3
#define DPAD_1_DOWN     4   // GPA4
#define SYS_LEFT        5   // GPA5
#define ANALOG_2_UP     6   // GPA6
#define ANALOG_1_DOWN   7   // GPA7

// MCP23017 Pin Mappings — Port B
#define DPAD_2_UP       8   // GPB0
#define DPAD_2_RIGHT    9   // GPB1
#define DPAD_2_CENTER   10  // GPB2
#define ANALOG_1_UP     11  // GPB3
#define ANALOG_2_DOWN   12  // GPB4
#define DPAD_2_DOWN     13  // GPB5
#define DPAD_1_LEFT     14  // GPB6
#define DPAD_2_LEFT     15  // GPB7

// -----------------------------------------------------------------------------
// ESP32-C6 NATIVE PIN MAPPINGS
// -----------------------------------------------------------------------------
#define PIN_BATTERY     0
#define PIN_USB_SENSE   1
#define PIN_BUZZER      2
// SYS_CENTRE was GPIO3 on the original ESP32 WROOM test rig, and separately
// gained a "Power Button" (GPIO21) during the C6 port instead of being moved
// to the real button's actual pin — leaving two names for the same physical
// button. Consolidated onto the real, wired GPIO: short press
// confirms/selects (or wakes from sleep); held ~1s during an active session
// terminates it; held 3s from Home/Apps Menu opens the shutdown confirm; also
// the deep/light-sleep wake source.
#define SYS_CENTRE      21
#define PIN_SDA         22   // XIAO ESP32-C6 silkscreen D4/SDA
#define PIN_SCL         23   // XIAO ESP32-C6 silkscreen D5/SCL
#define PIN_INTA        17
#define PIN_INTB        19

// =============================================================================
// SCREEN STATE ENUM
// Apps entered from the APPS submenu only; Transmitter/Settings kept separate
// =============================================================================
enum ScreenState {
  // AIO Main Screens
  PAGE_BOOT,
  PAGE_OPTIONS,       // Main hub: TRANSMITTER | APPS | SETTINGS

  // Apps submenu (entered when APPS is selected)
  SCREEN_APPS_MENU,
  SCREEN_STOPWATCH,
  SCREEN_TIMER,
  SCREEN_TIMER_ALERT,

  // WiFi app (entered from Apps menu)
  SCREEN_WIFI_CONFIRM,
  SCREEN_WIFI_SCANNING,
  SCREEN_WIFI_RESULTS,
  SCREEN_WIFI_PASSWORD,
  SCREEN_WIFI_KEYBOARD,
  SCREEN_WIFI_HOME,
  SCREEN_WIFI_TOGGLE_CONFIRM,
  SCREEN_WIFI_NTP,
  SCREEN_WIFI_AUTO_CONFIRM,
  SCREEN_WIFI_FORGET_CONFIRM,

  // Calculator
  SCREEN_CALCULATOR,
  SCREEN_CALCULATOR_SCI,

  // Settings (entered from PAGE_OPTIONS)
  SCREEN_SETTINGS_MENU,
  SCREEN_SETTINGS_FREQ,
  SCREEN_SETTINGS_MANAGE_WIFI,

  // Transmitter Screens
  SCREEN_TX_MENU,
  // WiFi UDP transmit flow
  SCREEN_TX_UDP_NOWIFI,
  SCREEN_TX_UDP_MODE,
  SCREEN_TX_UDP_IP,
  SCREEN_TX_UDP_CONTROL,
  SCREEN_BLE_ADVERTISING,
  SCREEN_BLE_CONNECTED,
  SCREEN_TX_SCANNING,
  SCREEN_TX_RESULTS,
  SCREEN_TX_PAIRING,
  SCREEN_TX_CONNECTED,
  // Smart Connect flow (dummy UI)
  SCREEN_SC_SCANNING,
  SCREEN_SC_RESULTS,
  SCREEN_SC_CONNECTING1,
  SCREEN_SC_PIN_ENTRY,
  SCREEN_SC_CONNECTING2,
  SCREEN_SC_CONNECTED,
  SCREEN_TX_STATUS,
  SCREEN_TX_CONTROL,
  SCREEN_TX_TELEMETRY,
  SCREEN_TX_TERMINATE,
  SCREEN_TX_TERMINATING,
  SCREEN_TX_FAILED,
  SCREEN_TX_RX_LOST,
  SCREEN_TX_WIFI_DISABLE,

  // Power button long-press (from PAGE_OPTIONS / SCREEN_APPS_MENU only)
  SCREEN_SHUTDOWN_CONFIRM,
  SCREEN_SHUTTING_DOWN
};

ScreenState currentScreen = PAGE_BOOT;

// =============================================================================
// GLOBAL STATE — AIO HUB
// =============================================================================
unsigned long bootStartTime  = 0;
unsigned long lastActivityTime = 0;
bool isDisplaySleep = false;
int page2Focus = 0; // 0=Transmitter, 1=Applications, 2=Settings

// Status bar icons — hidden (false) until Bluetooth / ESP-NOW are implemented
bool bleStatusActive    = false;
bool espNowStatusActive = false;

int simulated_analog_1 = 0;
int simulated_analog_2 = 0;

// =============================================================================
// GLOBAL STATE — TRANSMITTER
// =============================================================================
// 2x2 menu grid:  0=ESP_NOW  1=SMART_CONNECT  2=WiFi UDP  3=BLE   (-1=Back)
int txMenuFocus = 0;
int txMenuScroll = 0;       // internal vertical scroll px (animates toward target)
unsigned long txScanStart = 0;
int txResultScroll = 0;
int txResultIndex = 0;
String txTargetName = "";
unsigned long txPairStart = 0;
unsigned long txConnectedStart = 0;
int txControlPage = 1; // 0=Status, 1=Control, 2=Telemetry
int txStatusScroll = 0;
int txTerminateFocus = 1; // 0=YES, 1=NO
unsigned long txTerminatingStart = 0;

// ---- Smart Connect UI ----
unsigned long scConnectStart = 0;
unsigned long scAuthStart = 0;
unsigned long scConnectedStart = 0;
int scPin[4] = {0, 0, 0, 0};
int scPinCursor = 0; // -1=Back, 0-3=digit slots, 4=OK

// ---- ESP-NOW / Smart Connect real protocol ----
static const uint8_t ESPNOW_BROADCAST[6] = {0xFF,0xFF,0xFF,0xFF,0xFF,0xFF};
bool espNowInitialized = false;
int txActiveMode = 0; // 1=ESP_NOW, 2=SMART_CONNECT
uint8_t txOwnMacBytes[6] = {0};
char txOwnMacStr[18] = "";
uint8_t txTargetMacBytes[6] = {0};
bool txPeerRegistered = false;

// Scan results
#define MAX_SCAN_RESULTS 10
struct ScanResult {
  uint8_t macBytes[6];
  char mac[18];
  char name[20];
};
ScanResult scanResults[MAX_SCAN_RESULTS];
volatile int scanResultCount = 0;
bool txScanning = false;

// Handshake (ESP_NOW)
int txHandshakeStep = 0;   // 0=send hello, 1=wait ack, 2=wait connok
int txHandshakeAttempt = 0;
unsigned long txHandshakeTime = 0;
volatile bool txAckReceived = false;
volatile bool txConnOkReceived = false;

// Handshake (Smart Connect)
volatile bool txPartialOkReceived = false;
volatile int txScPinResult = 0; // 0=waiting, 54=ok, 55=fail
unsigned long scLastReqResend = 0;  // ConnectReq retransmit timer (CONNECTING1)
unsigned long scLastPinResend = 0;  // PinSubmit retransmit timer (CONNECTING2)

// "Disable WiFi?" gate before entering a transmit mode
int txWifiDisableFocus = 0;   // 0 = Yes, 1 = No
int txPendingMode = 0;        // 1 = ESP_NOW, 2 = SMART_CONNECT (mode to start after Yes)

// Power button (SYS_CENTRE) long-press -> shutdown confirm
unsigned long powerBtnPressStart = 0;   // 0 = not currently held
bool powerBtnLongPressHandled = false;  // gates re-trigger while still held past 3s
bool powerBtnWaitingRelease = false;    // true right after a light-sleep wake — the
                                         // wake press must be fully released before
                                         // it can start counting toward a fresh 3s
                                         // long-press again (otherwise a wake press
                                         // held through boot re-triggers shutdown
                                         // the instant PAGE_OPTIONS is reached)
int shutdownConfirmFocus = 0;           // 0 = Yes, 1 = No
ScreenState shutdownReturnScreen = PAGE_OPTIONS; // where "No" returns to
unsigned long shuttingDownStart = 0;    // "Shutting Down..." splash entry time

// Active session
bool txSessionActive = false;
unsigned long lastTxCmdSend = 0;

// Telemetry from receiver
char txTelemetryStr[64] = "NO DATA";
volatile bool txNewTelemetry = false;
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
void loop() {
  readMcpState(); // one I2C transaction for all 16 inputs; everything below reads the cache
  readButtons();

  // ---------- Activity + sleep logic ----------
  bool anyPress = buttonJustPressed[0] || buttonJustPressed[1] ||
                  buttonJustPressed[2] || buttonJustPressed[3] || buttonJustPressed[4];

  // Also reset sleep for any secondary button activity
  bool secondaryActive = mcpBtn(SYS_LEFT) ||
                         mcpBtn(SYS_RIGHT) ||
                         (digitalRead(SYS_CENTRE) == LOW) || // native GPIO, not on the expander
                         mcpBtn(ANALOG_1_UP) ||
                         mcpBtn(ANALOG_1_DOWN) ||
                         mcpBtn(ANALOG_2_UP) ||
                         mcpBtn(ANALOG_2_DOWN);

  if (anyPress || secondaryActive) {
    lastActivityTime = millis();
    if (isDisplaySleep) {
      isDisplaySleep = false;
      display.ssd1306_command(SSD1306_DISPLAYON);
      // Screen was already forced to Home at the moment sleep was entered
      // (below), so waking just has to turn the panel back on and swallow
      // the wake press — no screen-state work needed here.
      for (int i = 0; i < 5; i++) buttonJustPressed[i] = false;
      return; // consume wake press
    }
  }

  bool inhibitSleep = (currentScreen == SCREEN_STOPWATCH && swRunning) ||
                      (currentScreen == SCREEN_TIMER && tmMode == TM_RINGING) ||
                      (currentScreen == SCREEN_TIMER_ALERT) ||
                      (currentScreen == SCREEN_WIFI_SCANNING) ||
                      (currentScreen == SCREEN_WIFI_PASSWORD && wifiConnecting) ||
                      (currentScreen == SCREEN_WIFI_NTP) ||
                      udpSessionActive || txSessionActive ||
                      txScanning ||
                      // Entire ESP_NOW / Smart Connect flow — these screens auto-advance
                      // on their own timers (handshake retries, splash screens, etc.)
                      // with no button press required, and the display-sleep early
                      // `return` below would otherwise freeze that state machine dead
                      // the moment the 10s idle timeout hit mid-flow.
                      (currentScreen >= SCREEN_TX_SCANNING && currentScreen <= SCREEN_TX_WIFI_DISABLE);

  if (!isDisplaySleep && currentScreen != PAGE_BOOT && !inhibitSleep) {
    if (millis() - lastActivityTime > 10000) {
      isDisplaySleep = true;
      // Force straight to Home the moment the screen goes dark — inhibitSleep
      // above guarantees we're always on an idle menu screen here, never mid
      // session, so this can never interrupt anything. Doing the reset here
      // (rather than on wake) means the framebuffer already holds Home by the
      // time the panel is off; nothing on the wake side can race or override it.
      // Panel is switched off BEFORE the redraw is pushed — SSD1306_DISPLAYOFF
      // only disables the panel drivers, the GDDRAM stays writable, so the
      // Home frame lands invisibly instead of flashing on screen first.
      display.ssd1306_command(SSD1306_DISPLAYOFF);
      currentScreen = PAGE_OPTIONS;
      isAnimating = false;
      animOffsetX = animOffsetY = 0;
      page2Focus = 0;
      renderFrame();
      display.display();
      return;
    }
  }
  if (isDisplaySleep) return;

  // ---------- Power button (long-press = shutdown confirm) ----------
  // Native GPIO (not on the MCP23017), so it needs its own held-duration
  // tracking rather than the buttonJustPressed[] edge array. Only arms the
  // confirm screen from the home hub or the apps menu, per spec.
  bool powerBtnDown = (digitalRead(SYS_CENTRE) == LOW);
  if (powerBtnWaitingRelease) {
    // Ignore entirely until the button that woke us from light sleep is
    // actually released — prevents a still-held wake press from being
    // re-read as a fresh long-press the moment boot reaches PAGE_OPTIONS.
    if (!powerBtnDown) powerBtnWaitingRelease = false;
    powerBtnPressStart = 0;
  } else if (powerBtnDown) {
    if (powerBtnPressStart == 0) powerBtnPressStart = millis();
    if (!powerBtnLongPressHandled && millis() - powerBtnPressStart > 3000 &&
        (currentScreen == PAGE_OPTIONS || currentScreen == SCREEN_APPS_MENU) && !isAnimating) {
      powerBtnLongPressHandled = true;
      shutdownReturnScreen = currentScreen;
      shutdownConfirmFocus = 0;
      lastActivityTime = millis();
      startAnimation(SCREEN_SHUTDOWN_CONFIRM, -64);
    }
  } else {
    powerBtnPressStart = 0;
    powerBtnLongPressHandled = false;
  }

  // ---------- Boot transition ----------
  // Do NOT return here — fall through so the render block below draws the boot
  // screen each frame and also renders the slide animation into PAGE_OPTIONS.
  if (currentScreen == PAGE_BOOT) {
    if (millis() - bootStartTime > 2000 && !isAnimating) {
      startAnimation(PAGE_OPTIONS, -64);
      lastActivityTime = millis();
    }
  }

  // ---------- WiFi scan polling ----------
  if (currentScreen == SCREEN_WIFI_SCANNING && !isAnimating) {
    lastActivityTime = millis();
    int result = WiFi.scanComplete();
    static bool scanRetried = false;
    if (result >= 0) {
      wifiScanResults = result;
      wifiListIndex = 0; wifiListScroll = 0;
      startAnimation(SCREEN_WIFI_RESULTS, -64);
      scanRetried = false;
    } else if (result == WIFI_SCAN_FAILED) {
      if (!scanRetried) {
        scanRetried = true;
        WiFi.scanNetworks(true, false, false, 80);
      } else {
        wifiScanResults = 0;
        startAnimation(SCREEN_WIFI_RESULTS, -64);
        scanRetried = false;
      }
    } else if (millis() - wifiScanStart > 8000) {
      WiFi.scanDelete();
      wifiScanResults = 0;
      startAnimation(SCREEN_WIFI_RESULTS, -64);
      scanRetried = false;
    }
  }

  // ---------- NTP sync polling ----------
  if (currentScreen == SCREEN_WIFI_NTP && !isAnimating) {
    lastActivityTime = millis();
    if (ntpSyncState == 0) {
      struct tm timeinfo;
      if (getLocalTime(&timeinfo, 0)) {
        ntpSyncState = 1;
        ntpSyncEnd   = millis();
      } else if (millis() - ntpSyncStart > 5000) {
        ntpSyncState = 2;
        ntpSyncEnd   = millis();
      }
    } else {
      if (millis() - ntpSyncEnd > 2000) {
        startAnimation(SCREEN_WIFI_HOME, -64);
        ntpSyncState = 0;
      }
    }
  }

  // ---------- WiFi UDP transmit (configurable Hz, runs regardless of screen/animation) ----------
  if (udpSessionActive && WiFi.status() == WL_CONNECTED) {
    unsigned long udpIntervalMs = 1000 / wifiUdpFreqHz;
    if (millis() - lastUdpSend >= udpIntervalMs) {
      lastUdpSend = millis();
      sendUdpControlPacket();
    }
  }

  // ---------- ESP-NOW transmit (runs regardless of screen/animation) ----------
  if (txSessionActive && espNowInitialized) {
    int freqHz = (txActiveMode == 1) ? espNowFreqHz : sconnectFreqHz;
    unsigned long intervalMs = 1000 / freqHz;
    if (millis() - lastTxCmdSend >= intervalMs) {
      lastTxCmdSend = millis();
      sendTxCommand();
    }

    // Telemetry watchdog — the receiver replies with telemetry to every command,
    // so no telemetry for 10s means it has dropped off (powered down / out of
    // range). Stop the session and surface the RX-lost page. Gated to the active
    // control screens so the teardown flow (terminate) isn't interrupted.
    if ((currentScreen == SCREEN_TX_CONTROL || currentScreen == SCREEN_TX_STATUS ||
         currentScreen == SCREEN_TX_TELEMETRY) &&
        (millis() - txLastTelemetryMs > 10000)) {
      Serial.println(F("[TX] No telemetry 10s — RX lost"));
      txSessionActive = false;
      removeTxPeer();
      txRxLostStart = millis();
      startAnimation(SCREEN_TX_RX_LOST, -64);
    }
  }

  // ---------- Timer tick ----------
  if (tmMode == TM_RUNNING) {
    unsigned long now   = millis();
    unsigned long delta = now - tmLastTick;
    if (tmRemainingMillis > delta) {
      tmRemainingMillis -= delta;
      tmLastTick = now;
    } else {
      tmRemainingMillis = 0;
      tmMode = TM_RINGING;
      currentScreen = SCREEN_TIMER_ALERT;
      if (isDisplaySleep) { display.ssd1306_command(SSD1306_DISPLAYON); isDisplaySleep = false; }
      lastActivityTime = millis();
      tmRingPhase = 0;
      tmRingNextStep = 0;
    }
  }

  // ---------- Timer ring buzzer ----------
  if (tmMode == TM_RINGING) stepTimerRingTone();

  // ---------- Input handling ----------
  if (!isAnimating) {
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

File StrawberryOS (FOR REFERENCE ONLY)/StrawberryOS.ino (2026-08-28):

// StrawberryOS - A smartwatch OS for ESP32
// Copyright (C) 2026 Ashutosh
//
// See the LICENSE file for more details.
#include <Arduino.h>
#include <Wire.h>
#include <SPI.h>
#include <RTClib.h>
#include <Adafruit_SSD1306.h>
#include <Adafruit_GFX.h>
#include <WiFi.h>
#include <HTTPClient.h>
#include <Preferences.h>
#include "time.h"
#include <NimBLEDevice.h>
#include <esp_sleep.h>
#include <driver/gpio.h>
#include <LittleFS.h>
#include <WiFiClientSecure.h>

#define SCREEN_WIDTH 128
#define SCREEN_HEIGHT 64
#define OLED_RESET -1
Adafruit_SSD1306 display(SCREEN_WIDTH, SCREEN_HEIGHT, &Wire, OLED_RESET);

RTC_DS3231 rtc;

#define BTN_UP 6
#define BTN_DOWN 9
#define BTN_LEFT 8
#define BTN_RIGHT 7
#define BTN_CENTER 10

volatile bool buttonStates[5] = {false, false, false, false, false};
const uint8_t buttonPins[5] = {BTN_UP, BTN_DOWN, BTN_LEFT, BTN_RIGHT, BTN_CENTER};
uint8_t statusIndex = 0;
bool isStatusActive = false;

enum ScreenState {
  SCREEN_WATCHFACE, SCREEN_MENU, SCREEN_STOPWATCH, SCREEN_TIMER, SCREEN_TIMER_ALERT,

  SCREEN_RADIO,
  SCREEN_RADIO_WIFI, SCREEN_WIFI_CONFIRM, SCREEN_WIFI_SCANNING,
  SCREEN_WIFI_RESULTS, SCREEN_WIFI_PASSWORD, SCREEN_WIFI_KEYBOARD,
  SCREEN_WIFI_HOME, SCREEN_WIFI_TOGGLE_CONFIRM,
  SCREEN_RADIO_BLE, SCREEN_RADIO_BLE_CONFIRM, SCREEN_RADIO_ESPNOW,

  SCREEN_POWER_HOME, SCREEN_WIFI_AUTO_CONFIRM, SCREEN_ESPNOW_AUTO_CONFIRM,
  SCREEN_POWER_MODE, SCREEN_POWER_MODE_HELP, SCREEN_ECO_EXIT_CONFIRM,
  SCREEN_WIFI_NTP,

  SCREEN_AI_CHAT, SCREEN_AI_THINKING, SCREEN_AI_WIFI_ERROR,
  SCREEN_CALCULATOR, SCREEN_CALCULATOR_SCI
};
ScreenState currentScreen = SCREEN_WATCHFACE;

bool lastButtonStates[5] = {false, false, false, false, false};
bool buttonJustPressed[5] = {false, false, false, false, false};

const int NUM_MENU_ITEMS = 6;
const char* menuItems[NUM_MENU_ITEMS] = {"Stopwatch", "Timer", "Radio", "AI Chat", "Calculator", "Lock"};
int menuIndex = 0;

unsigned long swStartTime = 0;
unsigned long swElapsedTime = 0;
bool swRunning = false;
int swFocus = 0;

enum TimerMode { TM_SETTING, TM_READY, TM_RUNNING, TM_RINGING };
TimerMode tmMode = TM_SETTING;
int tmHours = 0, tmMinutes = 0, tmSeconds = 0;
int tmActiveUnit = 2;
int tmFocus = 1;
unsigned long tmRemainingMillis = 0;
unsigned long tmLastTick = 0;
unsigned long tmSetPressStart = 0;
bool tmLongPressTriggered = false;

bool isAnimating = false;
int animOffsetY = 0;
int animTargetY = 0;
ScreenState animNextScreen = SCREEN_WATCHFACE;

unsigned long lastActivityTime = 0;
const unsigned long DISPLAY_TIMEOUT_MS = 5000;
bool displayOn = true;

enum KBMode { KB_LOWER, KB_UPPER, KB_SYMBOL };
KBMode currentKBMode = KB_LOWER;
int kbCursorRow = 0, kbCursorCol = 0;

const char* kbLower[4][11] = {
  {"q","w","e","r","t","y","u","i","o","p","."},
  {"a","s","d","f","g","h","j","k","l",",","?"},
  {"z","x","c","v","b","n","m","CL","CR","^","BS"},
  {"1","2","3","4","5","6","7","8","9"," ","EN"}
};
const char* kbUpper[4][11] = {
  {"Q","W","E","R","T","Y","U","I","O","P","."},
  {"A","S","D","F","G","H","J","K","L",",","?"},
  {"Z","X","C","V","B","N","M","CL","CR","^","BS"},
  {"!","@","#","$","%","^","&","*","("," ","EN"}
};
const char* kbSymbol[4][11] = {
  {"1","2","3","4","5","6","7","8","9","0","~"},
  {"@","$","%","&","*","-","+","=","!","|","\\"},
  {"/","?",";",":","'","(",")","CL","CR","^","BS"},
  {"[","]","{","}","<",">","#","_","."," ","EN"}
};

bool wifiAutoOn = false;
bool espNowAutoOn = false;
String lastConnectedSSID = "";
bool wifiEnabled = false;
int wifiScanResults = 0;
int wifiListIndex = -1;
int wifiListScroll = 0;
String wifiTargetSSID = "";
String wifiPassword = "";
String wifiStatusMsg = "";
bool wifiConnecting = false;
unsigned long wifiScanStart = 0;
unsigned long wifiConnectStartTime = 0;
int wifiHomeCursor = -1;
int wifiConfirmCursor = 0;
int wifiToggleCursor = 0;
int wifiPasswordCursor = 1;
unsigned long ntpSyncStart = 0;
unsigned long ntpSyncEnd = 0;
int ntpSyncState = 0;
int wifiRetryCount = 0;

String kbInputBuffer = "";
int kbTextCursor = 0;
int kbScrollOffset = 0;
ScreenState kbReturnScreen = SCREEN_WIFI_PASSWORD;

NimBLEServer* pBleServer = NULL;
NimBLECharacteristic* pBleNameCharacteristic = NULL;
NimBLECharacteristic* pPhoneNameCharacteristic = NULL;
NimBLECharacteristic* pDisplayCharacteristic = NULL;
NimBLECharacteristic* pMirrorControlCharacteristic = NULL;
volatile bool bleConnected = false;
volatile bool mirroringActive = false;
unsigned long lastMirrorUpdate = 0;
const int MIRROR_INTERVAL = 100; // 10 FPS
String bleRemoteAddress = "";
String bleDeviceName = "Ashutosh's Smartwatch";
String bleRemoteDeviceName = "None";
bool bleSettingAccess = false;
int bleHomeCursor = 0;
int bleConfirmMode = 0;
int bleConfirmCursor = 0;
bool bleDisconnecting = false;

class PhoneNameCallbacks: public NimBLECharacteristicCallbacks {
    void onWrite(NimBLECharacteristic* pCharacteristic) {
        std::string value = pCharacteristic->getValue();
        if (value.length() > 0) {
            bleRemoteDeviceName = String(value.c_str());
            Serial.print("Phone Name updated: ");
            Serial.println(bleRemoteDeviceName);
        }
    }
};

Preferences prefs;
const int MAX_SAVED_NETS = 5;
String savedSSIDs[MAX_SAVED_NETS];
String savedPWDs[MAX_SAVED_NETS];
int savedNetCount = 0;

bool pingerStatus[5] = {false, false, false, false, false};
bool internetOK = false;
volatile bool statusChanged = false;

const char* ntpServer = "pool.ntp.org";
const long gmtOffset_sec = 19800;
const int daylightOffset_sec = 0;

int radioCursor = 0;
int powerHomeCursor = 0;

enum PowerModeType { POWER_NORMAL, POWER_ECO };
PowerModeType currentPowerMode = POWER_NORMAL;
int powerModeButtonCursor = 0;
bool ecoModeActive = false;
unsigned long ecoModeSleepStart = 0;
const unsigned long ECO_MODE_SLEEP_DURATION = 5000;
unsigned long ecoExitPressStart = 0;
const unsigned long ECO_EXIT_PRESS_DURATION = 5000;
int ecoExitConfirmCursor = 1;
unsigned long ecoDeepSleepStart = 0;
const unsigned long ECO_DEEP_SLEEP_DELAY = 500;

int aiMsgCount = 0;
int aiChatScroll = 0;
bool aiScrollMode = false;
int aiCursor = 0;
String aiInputText = "";
bool aiThinking = false;
unsigned long aiThinkStart = 0;
String aiResponse = "";
volatile bool aiResponseReady = false;
volatile bool aiResponseError = false;
int aiWifiErrorType = 0;
int aiWifiErrorCursor = 1;
const char* GROQ_API_KEY = "YOUR_GROQ_API_KEY";
const int AI_MAX_MESSAGES = 500;
String aiCache[5];
int aiCacheScrollUsed = -1;

// Calculator variables
int calcCursorRow = 0, calcCursorCol = 0;
String calcInput1 = "";
String calcInput2 = "";
char calcOp = ' ';
bool calcIsOpSet = false;
bool calcError = false;

int calcSciRow = 0, calcSciCol = 0;

// SCI functions grid: 3 rows x 2 cols
const char* sciGrid[3][2] = {
  {"x^2",  "sqrt"},
  {"pi",   "x^3"},
  {"cbrt", "BACK"}
};

const char* calcGrid[5][4] = {
  {"7",   "8",  "9",   "/"},
  {"4",   "5",  "6",   "*"},
  {"1",   "2",  "3",   "-"},
  {"0",   ".",  "+",   "="},
  {"<--", "C",  "DEL", "SCI"}
};
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
